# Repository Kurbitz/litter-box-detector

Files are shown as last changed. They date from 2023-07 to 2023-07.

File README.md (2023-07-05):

# litter-box-detector
This project was created as my project for the course Introduction to Applied Internet of Things at Linnaeus University in 2023.
To read more about the project, please read the [report](https://hackmd.io/xFK_AZmkQUyGTrr6Fm0LrA)

## Files

- code/ - Contains the code for the project
- models/ - Contains the 3D models for the project, both for perfboard and breadboard (STL and STEP)
- schematics/ - Contains the electrical schematics for the project
- docker/ - Contains the docker-compose files used to run the server-side code

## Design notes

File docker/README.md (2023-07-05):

### Installing Docker and Docker Compose
Getting Docker up and running on Ubuntu is very easy. You can find instructions on how to do it [here](https://docs.docker.com/engine/install/ubuntu/). Once you've installed Docker you'll need to install Docker Compose. You can find instructions on how to do that [here](https://docs.docker.com/compose/install/).

### Setting up the server stack
Once you've installed Docker and Docker Compose you're ready to set up the server stack. You can find the Docker Compose files in the GitHub-repository. 

The stack is split up into three different Docker Compose files. One for the Mosquitto, one for the TIG-stack and one for Node-RED. This is done so that I can easily tear down and rebuild the TIG-stack without having to rebuild the entire stack. This is useful when I want to make changes to one part of the stack without having to rebuild the entire thing, cutting down on downtime. To assist other people in setting up the stack I plan on creating a script that will automatically pull the latest version of the stack from GitHub and set it up. I'll update this section once I've done that.

To set up the stack you'll either need to clone the GitHub-repository or create the directory structure manually. If creating the directory structure manually you'll need to copy the files from the GitHub-repository into the correct directories.
The directory structure should look something like this:
```
├── mosquitto
│   ├── data
│   ├── log
│   ├── config
│   │   ├── password.txt
│   │   └── mosquitto.conf
│   └── docker-compose.yml
├── nodered
│   ├── data
│   └── docker-compose.yml
└── tig-stack
    ├── telegraf
    │   └── telegraf.conf
    ├── entrypoint.sh
    ├── .env
    └── docker-compose.yml
```

Once you've set up the directory structure you can start each part of the stack by running: 
```
docker-compose up -d
```

The ```-d``` flag tells Docker Compose to run the containers in the background. If you want to see the logs from the containers in your shell you can omit the ```-d``` flag.

### Configuration
The configuration files for each part of the stack can be found in the GitHub-repository. You'll need to make a few changes to the configuration files before you can start the stack.

#### Mosquitto
In the mosquitto directory you'll find a mosquitto.conf file. This is the configuration file for Mosquitto. You'll need to change the ```allow_anonymous``` setting to ```false``` and uncomment the ```password_file``` setting. Run the following command to generate a password file:

```bash
docker compose exec mosquitto mosquitto_passwd -b /mosquitto/config/password.txt user password
docker compose restart mosquitto
```
With "user" and "password" being the username and password you want to use. You can change these to whatever you want. Just make sure to change them in the NodeMCU code as well.

Mosquitto will start on port 1883 by default. If you want to change this you'll need to change the ```ports``` setting in the docker-compose.yml file.

#### TIG-stack
Change the variables with the ```CHANGE_ME``` placeholder in the .env and telegraf.conf files to whatever your are using. You can leave the rest of the variables as they are.

Influx will start on port 8086 by default and Grafana will start on port 3000. If you want to change this you'll need to change the ports defined in the .env file.

#### Node-RED
Node-RED needs basically no configuration. You can access the Node-RED editor by going to ```http://<server-ip>:1880``` in your browser. You can find more information on how to use Node-RED [here](https://nodered.org/docs/user-guide/).

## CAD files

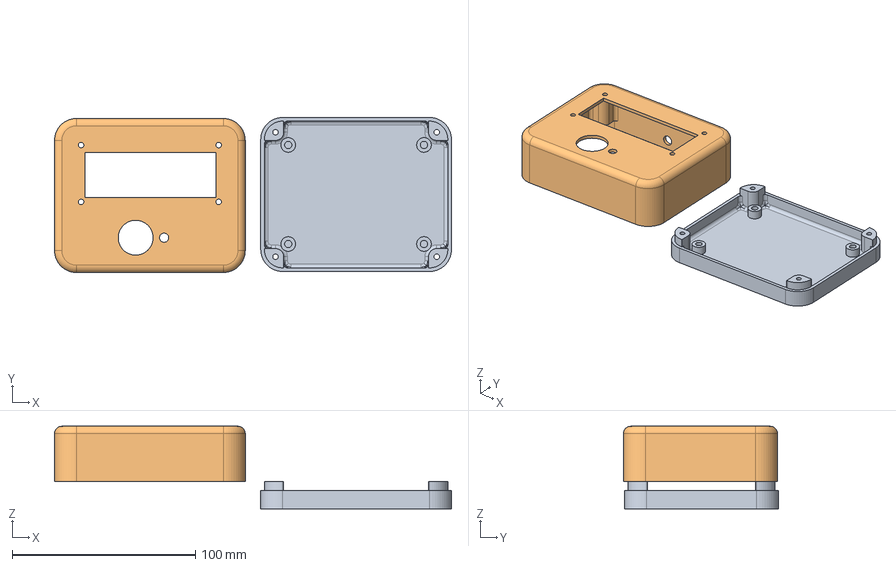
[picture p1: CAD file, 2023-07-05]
models/STEP/Litterbox_perfboard.step
216.4 x 84.6 x 45.0 mm

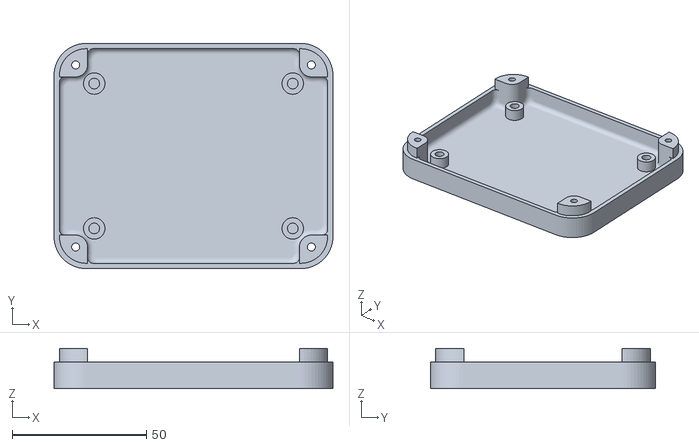
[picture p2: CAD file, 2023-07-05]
models/STL/LitterBox-perfboard-bottom.stl
104.0 x 84.0 x 15.0

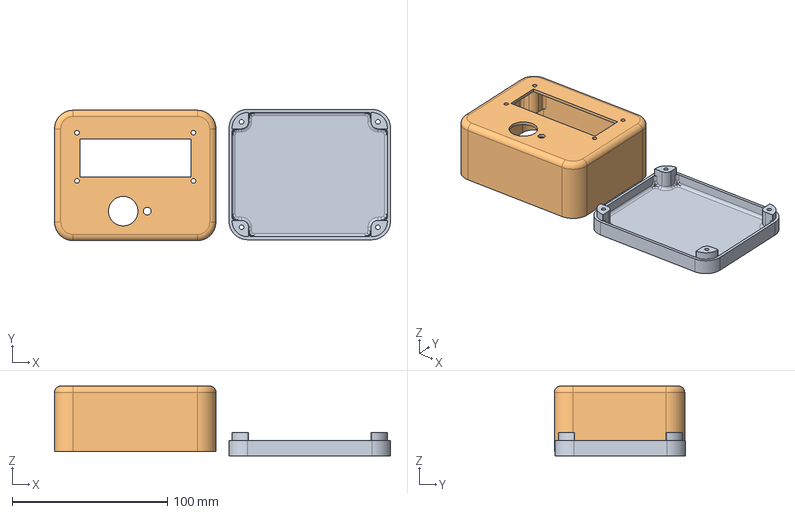
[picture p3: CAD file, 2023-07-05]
models/STEP/Litterbox_breadboard.step
216.4 x 84.6 x 45.0 mm

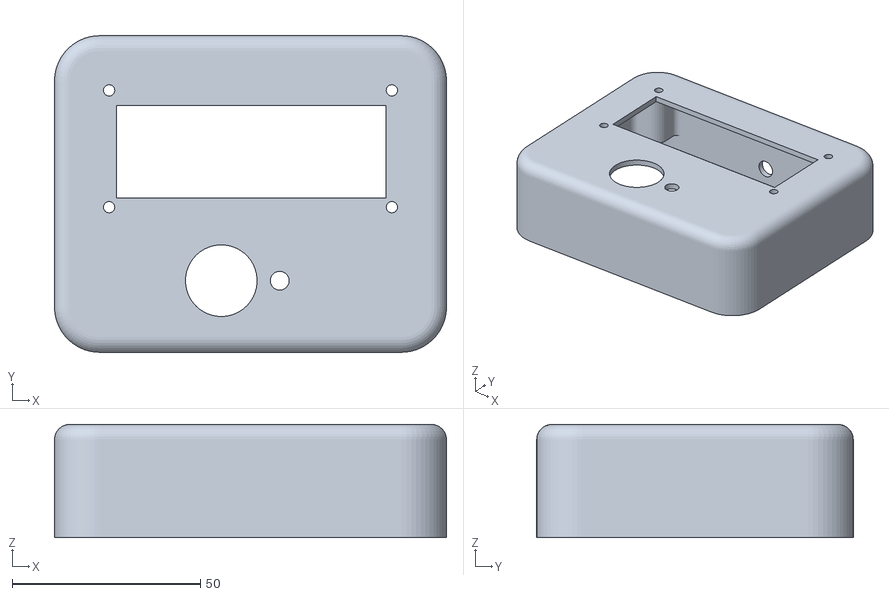
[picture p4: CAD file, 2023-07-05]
models/STL/LitterBox-perfboard-top.stl
104.0 x 84.0 x 30.0

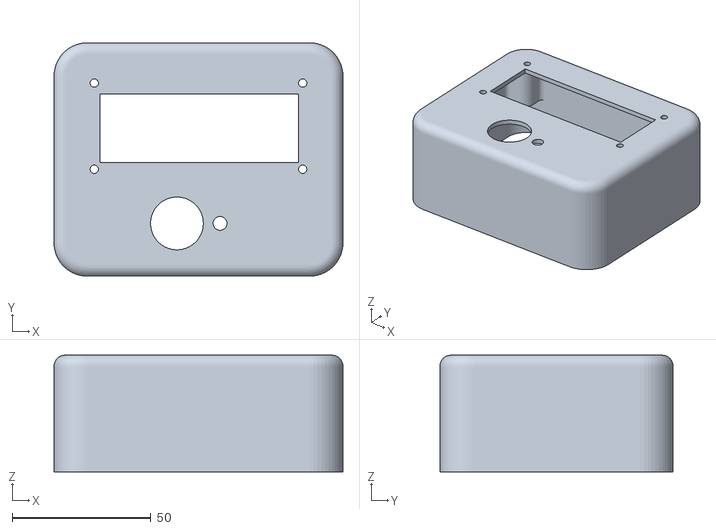
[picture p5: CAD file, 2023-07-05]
models/STL/LitterBox-breadboard-top.stl
104.0 x 84.0 x 42.0

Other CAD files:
models/STL/LitterBox-breadboard-bottom.stl

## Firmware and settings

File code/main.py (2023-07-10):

"""Litterbox monitor program for ESP8266."""
import json
import utime
import urequests as requests
from machine import Pin, unique_id, reset, I2C, Timer
from micropython import const
from dht import DHT11
from umqtt.simple import MQTTClient
from ubinascii import hexlify
from lib import config, i2c_lcd


class SensorState:
    reset_detected: bool = False
    button_1_ticks: int = 0
    motion_last_timestamp: int = 0
    reset_last_timestamp: int = 0
    motion_detected = False


DEBOUNCE_MS = const(300)  # Debounce time for the button in milliseconds
I2C_ADDR = const(
    0x27
)  # I2C address of the LCD display, check with i2c.scan() if this doesn't work

CLIENT_ID = hexlify(unique_id())  # Unique ID of the ESP8266
led = Pin(2, Pin.OUT)  # LED on GPIO2
led.off()  # Turn off the LED

dht = DHT11(Pin(14))  # DHT11 sensor on GPIO14
pir = Pin(12, Pin.IN)  # PIR sensor on GPIO12

button_1 = Pin(13, Pin.IN)  # Button on GPIO13

sdaPin = Pin(4)  # I2C SDA pin
sclPin = Pin(5)  # I2C SCL pin
i2c = I2C(sda=sdaPin, scl=sclPin, freq=10000)  # Initialise I2C
lcd = i2c_lcd.I2cLcd(
    i2c=i2c, i2c_addr=I2C_ADDR, num_lines=2, num_columns=16
)  # Initialise LCD display

backlight_timer = Timer(1)  # Timer for turning off the LCD backlight after a short time
debounce_timer = Timer(2)  # Timer for debouncing the button

# Initialise the MQTT client
mqtt_client = MQTTClient(
    CLIENT_ID,
    config.MQTT_BROKER,
    keepalive=60,
    user=config.MQTT_USER,
    password=config.MQTT_PASSWORD,
)


def main():
    # On startup, display a startup message on the LCD.
    # This serves two purposes:
    # 1. It looks cool
    # 2. The PIR sensor is very sensitive on startup, and will trigger a lot of
    #   false positives. This gives the sensor time to settle.
    display_startup_message()

    # Try to connect to the MQTT broker. If it fails, reset the device.
    try:
        mqtt_client.connect()
    except Exception as ex:
        print("Error connecting to MQTT broker:", ex)
        reset_device()

    # Initialise the state object.
    state = SensorState()
    state.button_1_ticks = utime.ticks_ms()

    # Set up the interrupts for the PIR sensor and the button.
    pir.irq(trigger=Pin.IRQ_FALLING, handler=lambda _: pir_handler(state))
    button_1.irq(
        trigger=Pin.IRQ_RISING, handler=lambda _: button_trigger(state, button_1)
    )

    # Get the last motion and reset timestamps from InfluxDB
    # If the timestamps could not be retrieved, the timestamps are set to 0.
    (
        state.motion_last_timestamp,
        state.reset_last_timestamp,
    ) = get_timestamps_from_influxdb()

    if state.motion_last_timestamp == 0 or state.reset_last_timestamp == 0:
        print("Error getting timestamps from InfluxDB")
        raise OSError

    # Main loop:
    while True:
        # Read the DHT sensor
        dht.measure()

        # Publish the data to MQTT
        mqtt_publish(
            "litterbox",
            {
                "motion_detected": int(state.motion_detected),
                "reset_pressed": int(state.reset_detected),
                "temperature": dht.temperature(),
                "humidity": dht.humidity(),
            },
        )

        now = get_now()
        # We've handled the events, reset the variables to False.
        # Set the timestamps to the current time.
        if state.motion_detected:
            state.motion_last_timestamp = now
            state.motion_detected = False
        if state.reset_detected:
            state.reset_last_timestamp = now
            state.reset_detected = False

        display_status(state)
        # Sleep for a while to keep the CPU usage low.
        utime.sleep(config.SLEEP_TIME)


#
def display_status(state: SensorState):
    now = get_now()
    motion_delta = now - state.motion_last_timestamp
    reset_delta = now - state.reset_last_timestamp

    motion_delta_tuple = utime.gmtime(motion_delta)
    reset_delta_tuple = utime.gmtime(reset_delta)

    print("Motion delta:", motion_delta_tuple)
    print("Reset delta:", reset_delta_tuple)

    reset_delta_hours = reset_delta_tuple[3] + (reset_delta_tuple[2] - 1) * 24
    reset_delta_minutes = reset_delta_tuple[4]

    # If the litterbox has been cleaned more recently than it has been used,
    # display a message saying that the litterbox is clean.
    if motion_delta > reset_delta:
        lcd_print_line(0, "Litterbox clean")
        lcd_print_line(1, f"{reset_delta_hours}h {reset_delta_minutes}m ago")
    # If the litterbox has been used more recently than it has been cleaned,
    # display the time since the litterbox was last used and last cleaned.
    else:
        motion_delta_hours = motion_delta_tuple[3] + (motion_delta_tuple[2] - 1) * 24
        motion_delta_minutes = motion_delta_tuple[4]

        lcd_print_line(0, f"Cat: {motion_delta_hours}h {motion_delta_minutes}m")
        lcd_print_line(1, f"Clean: {reset_delta_hours}h {reset_delta_minutes}m")
        # If the litterbox has not been cleaned for a long time, turn on the LED
        # to warn the user that the litterbox needs to be cleaned.
        if (
            state.reset_last_timestamp < state.motion_last_timestamp
            and motion_delta > config.LED_WARNING_THRESHOLD
        ):
            led.on()
        else:
            led.off()


# Print a line of text to the LCD display.
# If the text is shorter than 16 characters, pad it with spaces.
def lcd_print_line(line: int, text: str):
    lcd.move_to(0, line)
    if len(text) < 16:
        text += " " * (16 - len(text))
    lcd.putstr(text)


# Get the last motion and reset timestamps from InfluxDB
# Returns a tuple of (motion_timestamp, reset_timestamp)
# If the timestamps could not be retrieved, returns (0, 0)
# TODO: Clean up this function
def get_timestamps_from_influxdb() -> tuple[int, int]:
    print("Getting timestamps from InfluxDB...")
    # These queries get the last entries in the database where motion was detected or the reset button was pressed.
    motion_query = 'from(bucket: "iot") |> range(start: -1y) |> filter(fn: (r) => r["mqtt"] == "esp8266/litterbox") |> filter(fn: (r) => r["host"] == "iot") |> filter(fn: (r) => r["_field"] == "motion_detected") |> filter(fn: (r) => r["_value"] == 1) |> last()'
    reset_query = 'from(bucket: "iot") |> range(start: -1y) |> filter(fn: (r) => r["mqtt"] == "esp8266/litterbox") |> filter(fn: (r) => r["host"] == "iot") |> filter(fn: (r) => r["_field"] == "reset_pressed") |> filter(fn: (r) => r["_value"] == 1) |> last()'

    # Headers for the HTTP request
    headers = {
        "Accept": "application/csv",  # We want the response in CSV format
        "Content-type": "application/vnd.flux",  # We are sending a Flux query
        "Authorization": f"Token {config.INFLUXDB_TOKEN}",  # We need to authenticate with InfluxDB
    }

    # Send the HTTP requests
    motion_response = requests.post(
        url=config.INFLUX_DB_API_QUERY_URL,
        headers=headers,
        data=motion_query,
        timeout=5,
    )
    reset_response = requests.post(
        url=config.INFLUX_DB_API_QUERY_URL,
        headers=headers,
        data=reset_query,
        timeout=5,
    )

    # If any of the requests failed, return (0, 0) (please give me monads in micropython)
    if motion_response.status_code != 200 or reset_response.status_code != 200:
        print("Error getting timestamps from InfluxDB:", motion_response.status_code)
        return (0, 0)

    print("Motion response:", motion_response.text)
    print("Reset response:", reset_response.text)

    # parase the csv responses
    motion_timestamp = influxdb_resonse_to_timestamp(motion_response.text)
    reset_timestamp = influxdb_resonse_to_timestamp(reset_response.text)

    print(f"Motion timestamp: {motion_timestamp} ({utime.gmtime(motion_timestamp)})")
    print(f"Reset timestamp: {reset_timestamp} ({utime.gmtime(reset_timestamp)})")

    return (motion_timestamp, reset_timestamp)


# Parse a CSV response from InfluxDB and return the timestamp
# This function is very fragile and will break if the response format changes.
def influxdb_resonse_to_timestamp(response: str) -> int:
    # Split the response into lines and get the first two lines
    response_lines = response.split("\r\n")[0:2]
    # Split the lines on commas and get the value of the "_time" field
    time_string = response_lines[1].split(",")[
        response_lines[0].split(",").index("_time")
    ]
    return time_string_to_timestamp(time_string)


# Convert a time string in the format "2021-05-01T12:00:00Z" to a timestamp
def time_string_to_timestamp(time_string: str) -> int:
    return utime.mktime(
        (
            int(time_string[0:4]),
            int(time_string[5:7]),
            int(time_string[8:10]),
            int(time_string[11:13]),
            int(time_string[14:16]),
            int(time_string[17:19]),
            0,
            0,
        )
    )


# Get the current time as a timestamp
def get_now() -> int:
    return int(utime.time())


# Display a startup message on the LCD display
def display_startup_message():
    lcd.backlight_on()
    lcd.clear()
    utime.sleep(1)
    lcd.putstr("Starting up")
    utime.sleep_ms(400)
    lcd.putstr(".")
    utime.sleep_ms(400)
    lcd.putstr(".")
    utime.sleep_ms(400)
    lcd.putstr(".")
    utime.sleep(3)
    lcd.clear()
    lcd.backlight_off()


# Publish a message to MQTT
# The message is a dictionary that is converted to JSON.
# The topic is prefixed with the TOPIC_PREFIX constant.
# The message is not retained by default.
def mqtt_publish(topic: str, message: dict[str, object], retain=False) -> None:
    payload = json.dumps(message)
    print(
        "Publishing:",
        payload,
        "to topic:",
        config.TOPIC_PREFIX + "/" + topic,
        "retain:",
        retain,
    )
    mqtt_client.publish(
        config.TOPIC_PREFIX + "/" + topic, payload.encode(), retain=retain
    )


# Called when the PIR sensor detects motion.
def pir_handler(state: SensorState):
    state.motion_detected = True
    print("Motion detected")


# Is called when the button is pressed and the IRQ is triggered.
def button_trigger(state: SensorState, button: Pin):
    # To prevent multiple triggers from a single button press, we check if the
    # button was pressed within the last DEBOUNCE_MS milliseconds.
    print(
        f"Button triggered, delta {utime.ticks_ms() - state.button_1_ticks + DEBOUNCE_MS}ms"
    )
    if utime.ticks_ms() < state.button_1_ticks + DEBOUNCE_MS:
        return
    state.button_1_ticks = utime.ticks_ms()

    debounce_timer.init(
        period=100,
        mode=Timer.ONE_SHOT,
        callback=lambda x: button_handler(
            timer=x,
            state=state,
            button=button,
            long_press_time=config.LONG_PRESS_TIME,
            short_press_callback=lambda _: short_press_handler(),
            long_press_callback=long_press_handler,
        ),
    )


# Called when the button is short pressed.
def short_press_handler():
    print("Short press handler called")
    lcd.backlight_on()
    backlight_timer.init(
        period=config.LCD_BACKLIGHT_TIMEOUT,
        mode=Timer.ONE_SHOT,
        callback=lambda _: lcd.backlight_off(),
    )


# Called when the button is long pressed.
def long_press_handler(state: SensorState):
    print("Long press handler called")
    lcd.backlight_on()
    lcd.clear()
    lcd.putstr("Cleaning mode!")
    # Wait for the button to be pressed again or for the timeout to expire.
    for _ in range(config.CLEANING_TIMEOUT):
        if button_1.value() == 1:
            break
        led.on()
        utime.sleep(1)
        led.off()
        utime.sleep(1)
    lcd.clear()
    lcd.putstr("Cleaning done!")
    state.reset_detected = True
    utime.sleep(5)


# Detects long and short button presses and calls the appropriate callback.
# The callback is passed the state object.
# TODO: Make a button class that encapsulates this functionality.
def button_handler(
    timer: Timer,
    state: SensorState,
    button: Pin,
    time_passed: int = 0,
    long_press_time=2000,
    short_press_callback=lambda x: None,
    long_press_callback=lambda x: None,
):
    print("Button handler called, time passed:", time_passed, "ms")
    if time_passed >= long_press_time:
        if button.value() == 0:
            print("Long press registered")
            long_press_callback(state)
            return
    elif button.value() == 0:
        print("Short press registered")
        short_press_callback(state)
        return
    state.button_1_ticks = utime.ticks_ms()
    timer.init(
        period=100,
        mode=Timer.ONE_SHOT,
        callback=lambda x: button_handler(
            timer=x,
            state=state,
            button=button,
            time_passed=time_passed + 100,
            long_press_time=long_press_time,
            short_press_callback=short_press_callback,
            long_press_callback=long_press_callback,
        ),
    )


def reset_device():
    print("Resetting...")
    lcd.clear()
    lcd.putstr("Resetting...")
    utime.sleep(5)
    reset()


# Start of program
if __name__ == "__main__":
    try:
        main()
    except OSError as e:
        print("Error: " + str(e))
        reset_device()

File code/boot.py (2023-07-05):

# boot.py -- run on boot-up
import gc  # Garbage collector
import urequests  # Used for HTTP requests
import utime  # Used to get the current time
from machine import reset  # Used to reset the board
import network  # Used to connect to the network
import ntptime  # Used to set the time
from lib import config  # Used to get the network credentials


def connect_to_network():
    sta_if = network.WLAN(network.STA_IF)
    if not sta_if.isconnected():
        print("connecting to network...")
        sta_if.active(True)
        sta_if.connect(config.SSID, config.WPA2_KEY)
        while not sta_if.isconnected():
            pass
    print("Network config", sta_if.ifconfig())


# TODO: Add a way to check if the network is connected
def http_get_test(url="http://detectportal.firefox.com/") -> bool:
    response = urequests.get(url)
    print(response.text)
    return response.status_code == 200


gc.collect()
connect_to_network()
try:
    if not http_get_test():
        raise OSError
except OSError:
    print("OSError: Failed to connect to the internet")
    reset()

ntptime.settime()
print("Time:", utime.localtime())

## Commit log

2023-07-05 Add models
    [LitterBox-breadboard-bottom.stl, LitterBox-breadboard-top.stl, LitterBox-perfboard-bottom.stl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]
2023-07-05 Add schematics
    [Litterbox.fzz]
2023-07-10 Change how the LED warning time is calculated
    Now checks if the box hasn't been cleaned since it's been used AND
    LED_WARNING_THRESHOLD seconds has passed since it's been used.
    This should give a better indicator that the box needs cleaning
2023-07-10 Increase InfluxDB query start time
    The parsing function would error out when no results were found within
    the timespan. Increasing this to a year should solve it. This entire
    solution could use a refactoring though as it's kinda janky.
    [main.py]
